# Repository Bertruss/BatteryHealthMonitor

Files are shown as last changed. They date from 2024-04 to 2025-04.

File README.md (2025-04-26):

## Battery Health Monitor

ATtiny45/85 based dedicated battery health monitor for embedded projects, with small status readout

# Setup Notes:
- lfuse set to 0xE2 to remove the DIV8 and set the clock to full 8mhz

*example: programming using the USBtinyISP via avrdude*
```
avrdude -c usbtiny -p t45 -U hfuse:w:0xE2:m
```
- The font data was intended to be written to eeprom on the chip to save flash, 
not knowing what the total compiled footprint of the code would be beforehand, I assumed I would need to be covetous of the limited 4k flash, and yet as development went on that seemed less and less necessary ¯\\_(ツ)_/¯. 

I used Microchip Studio for a lot of this development. If you want to not clear the eeprom every time you reflash the program storage, set the eeprom protect bit:

```
avrdude -c usbtiny -p t45 -U hfuse:w:0xD7:m
```

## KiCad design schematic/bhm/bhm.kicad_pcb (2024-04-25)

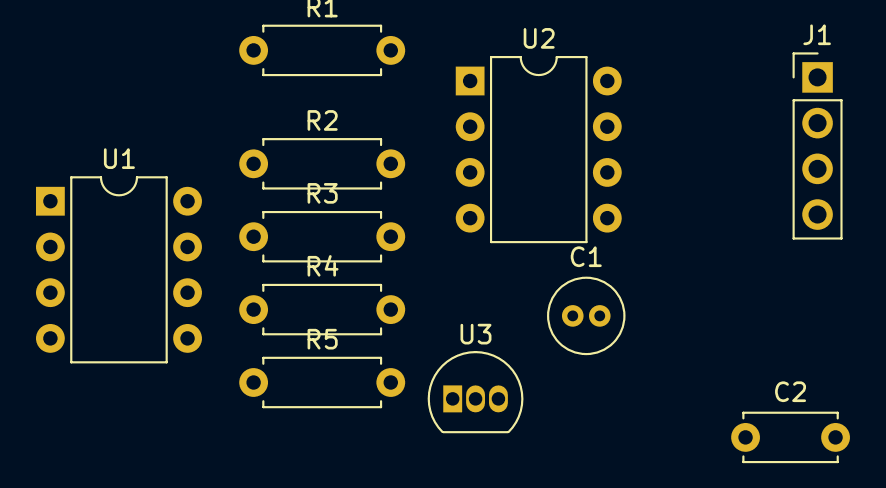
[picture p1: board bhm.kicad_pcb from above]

Board: 2 copper layers, 11 parts (0 on the bottom side), 9 nets, no tracks yet.

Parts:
C1: .33uf; C_Radial_D4.0mm_H7.0mm_P1.50mm
C2: .01uf; C_Disc_D5.0mm_W2.5mm_P5.00mm
J1: Conn_01x04; PinHeader_1x04_P2.54mm_Vertical
R1: 10k; R_Axial_DIN0207_L6.3mm_D2.5mm_P7.62mm_Horizontal
R2, R3, R4, R5: 300k; R_Axial_DIN0207_L6.3mm_D2.5mm_P7.62mm_Horizontal
U1: LM358; DIP-8_W7.62mm
U2: ATtiny45-20P; DIP-8_W7.62mm
U3: LM78L05_TO92; TO-92_Inline

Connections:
+8.4V: C1.1, R5.1, U1.8 (V+), U3.3 (VI)
GND: C1.2, C2.2, J1.4, R4.2, U1.4 (V-), U2.4 (GND), U3.2 (GND)
unnamed: J1.1, U2.5 (AREF/PB0)
unnamed: J1.2, U2.7 (PB2)
unnamed: C2.1, J1.3, R1.1, R3.1, U2.8 (VCC), U3.1 (VO)
unnamed: R4.1, R5.2, U1.3 (+)
unnamed: R2.2, R3.2, U1.2 (-)
unnamed: R2.1, U1.1, U2.2 (XTAL1/PB3)
unnamed: R1.2, U2.1 (~RESET/PB5)

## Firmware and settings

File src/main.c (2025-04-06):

#include "../include/fcpu.h"
#include "../include/TinyTWI.h"
#include "../include/TinyADC.h"
#include "../include/bhmDisplay.h"
#include "../include/bhmUtils.h"
#include "../include/SSD1306_driver.h"
#include <stdbool.h>
#include <avr/io.h>
#include <avr/sleep.h>
#include <util/delay.h>
#include "../include/bhmADC.h"

ISR(WDT_vect){ // toggle off the interrupt
	// watchdog timer interrupt disables automatically
    // sleep is disabled on wake via watchdog
}

int main(){
    cli(); // global interrupt disable
	//low_speed();
    twi_init(); // Initialize i2c
    adc_init(); // Configure ADC
	bhm_init(); // bhm specific configurations
    SSD1306_init(); // Setup the screen
	SSD1306_clear(); // Clear the screen mem
	configure_WDT_interrupt(); // configure timer based interrupt to wake sleep
	sei();
	bool test = 1;
	// Battery charge estimation 
	uint64_t total_charge_estimate = Ah; // assumption on bootup is that we start from full charge
	
	while(1){
		//test = !test; 
        uint32_t voltage = measure_battery_voltage();
        uint32_t current = measure_current_draw();
        uint8_t percent = basic_charge_estimate(voltage);
		//uint8_t percent = adv_charge_estimate(voltage, current, &total_charge_estimate);
		bool batt_warn = percent > 15 ? false : true; // below 15% trigger battery warning
		//calculate battery percentage estimate
        //calculate time-to-empty
        //update screen
		// ideas:
        // measure cell voltage O
        // transmit "bat low" if needed O
        // low power shut-off? X
        // low power beep? X
        // sleep for 500ms? update screen O
		update_display(percent, batt_warn, voltage, current);
		sleep_pause(); // 1s sleep pause
		_delay_ms(80);// acounting for other timing overhead, to reach 1.5s 
		
	}
}

void WDT_interrupt_enable(){
	 // enable the watchdog timer interrupt for sleep wake-up
	 WDTCR |= (1 << WDIE);
}				

void WDT_interrupt_disable(){
	WDTCR &= ~(1 << WDIE); // enable the watchdog timer interrupt for sleep wake-up
}

void configure_WDT_interrupt(){
	// TODO: consider configurable sleep cycle
    // TODO: PRR |= () //consider further power reduction
	// WDP3 WDP2 WDP1 WDP0
    WDTCR |= (1 << WDP2) | (1 << WDP1); //1 sec
}

void low_speed(){
	CLKPR = 0x80; // enable clk prescaler manipulation
	//(1 << CLKPCE) & !(1 << CLKPS3) & !(1 << CLKPS2) & !(1 << CLKPS1) & !(1 << CLKPS0);
	CLKPR |= (1 << CLKPS2); // | (1 << CLKPS0);
}

// triggers sleep mode with WDT triggered wake 
void sleep_pause(){
	cli();
	WDT_interrupt_enable();
	set_sleep_mode(SLEEP_MODE_IDLE);
	sei();
	sleep_enable();
	sleep_cpu(); //start slept conversion
	sleep_disable(); // wake
	WDT_interrupt_disable();
	cli();
}

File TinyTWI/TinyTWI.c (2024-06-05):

#include "TinyTWI.h"
#include "fcpu.h"
#include <stdint.h>
#include <stdbool.h>
#include <util/delay.h>

// fast mode, delays shortened because of other overhead 
#define __dwell_long() _delay_us(1.3) //low 1.3ns
#define __dwell_short() _delay_us(.8) //high .6ns

// refer to section 15 (pg.108) of the ATtiny25/45/85 Datasheet for more information

void twi_init(void){
    //initialize USI for I2C/TWI
	// Set the data register on the USI port
    USIDR = 0xFF;
    
    //initialize sda and scl to "high", default state
    PORT_TWI  |= (1 << SCL) | (1 << SDA);

	//intialize Data Direction on sda and scl as output val
	DDR_TWI |= (1 << SCL) | (1 << SDA);

    // Set the Control reg 
    USICR = (1 << USIWM1)| //Set the wire mode to TWI or I2C
            (1 << USICS1)| //set "external, pos-edge" clock source
            (1 << USICLK); //and set the 4-bit counter clk to software gen, via the (USITC) register
    // NOTE: for the sake of the 4-bit counter, this is an "external clock", 
    // so the counter is triggered on both edges. Hence a 4-bit (0-15 value) counter to count
    // shifting in and out an 8-bit value. The counter rolls over to 16 and triggers the overflow flag, 
    // which you can check to see if a full byte has been r/w

    // Set the status register
    /* TODO: experiment with pruning this.
    / USIPF and USIDC flags should never be set such that they need clearing in
    / this application. supposedly these are useful for multi-master arbitration but 
    / that won't appear in this programs intended use case.
    */
    USISR = (1 << USISIF) | //Clear the Start Condition Interrupt Flag
            (1 << USIOIF) | //Clear the Counter Overflow Interrupt Flag
            (1 << USIPF) | //Clear the Stop Condition Flag
            (1 << USIDC); //Clear Data Output Collision
}


void twi_disable(void){
	USICR &= !(1 << USIWM1); // disable TWI
}

void twi_enable(void){
	USICR |= (1 << USIWM1); // enable TWI
}

void twi_start(void){
    // outputs i2c start condition
    PORT_TWI &= ~(1 << SDA); // set SDA low
	__dwell_long();
    PORT_TWI &= ~(1 << SCL); // set clock low
	while ((PIN_TWI & (1 << SCL)) != 0); // wait for clock to pull low
	// other devices on the bus may hold clock high until they are ready, '
	// hence this wait.
	__dwell_long();
	//potentially, return status of start condition interrupt flag, start condition detection
}

void twi_stop(void){
    // outputs i2c stop condition
	USIDR = 0xff; //pulls SDA high?
	DDR_TWI |= (1 << SDA); //set SDA write
	PORT_TWI &= ~(1 << SDA); // set SDA low
	PORT_TWI |= (1 << SCL); // set SCL high
    while ((PIN_TWI & (1 << SCL)) == 0); //wait for SCL high
    __dwell_short();
    PORT_TWI |= (1 << SDA); // pull SDA high
    __dwell_long(); // just in case time-padding
}

uint8_t twi_byte_transfer(uint8_t buff, bool bit, enum xfer_type mode){
    //params:
    // buff - potential byte to write
    // bit - r/w single bit?
    // mode - transfer type is READ or WRITE
	USISR = (1 << USISIF) |
			(1 << USIOIF) |
			(1 << USIPF) |
			(1 << USIDC);
	USIDR = buff;
	
    if(mode == WRITE){
        DDR_TWI |= (1 << SDA); // data direction : write
		USIDR = buff; // move the data to the USI data register
    }
	else{ // READ
        DDR_TWI &= ~(1 << SDA); // data direction : read
    }

    if(bit){ //only read or write single bit
        USISR |= (0xE << USICNT0); //overflow with 1 bit
    }   
	
    // following loop will shift the data register onto the sda line (or vice versa depending on ddr setting) by toggling the clock
	PORT_TWI |= (1 << SDA); // "Release" sda
    do {
		__dwell_short();
		USICR = (1 << USIWM1) | (1 << USICS1) | (1 << USICLK) | (1 << USITC); // toggle the clock
		while ((PIN_TWI & (1 << SCL)) == 0); //wait for the clock to pull high
        __dwell_long();
        USICR = (1 << USIWM1) | (1 << USICS1) | (1 << USICLK) | (1 << USITC); // toggle the clock /* USICR = (1 << USIWM1) | (1 << USICS1) | (1 << USICLK) | (1 << USITC); */	
	}
    while((USISR & (1 << USIOIF)) == 0); // Check for counter overflow
	
    //__dwell_long();
    uint8_t data = USIDR;
    return data;
}

bool twi_transmission (uint8_t addr, uint8_t* buff, uint16_t length, enum xfer_type mode){
    twi_start();
    // Transmission Setup
    // Concatenate the address and transmit mode
    uint8_t ack;
	addr = (addr << 1) | mode;
    twi_byte_transfer(addr, false, WRITE);
	if(twi_byte_transfer(0x00, true, READ) != 0x00){ // check ack
		twi_stop();
		return false; // ACK failed
    }
	
    // Read or Write loop
    do{
        // read/write next byte
        *buff = twi_byte_transfer(*buff, false, mode);
		ack = twi_byte_transfer(0x00, true, 0x01^mode); // read/write ack bit
        buff++; // shift buffer pointer/index forward
		length--;
    }while(length && (ack == 0x00));
	
    //if read mode, end with NACK
    if(mode == READ){
        twi_byte_transfer(0x01, true, WRITE);
    }
	
    twi_stop();
	return (ack == 0x00);
}

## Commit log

2024-03-05 implementing small USI I2C
2024-03-06 WIP i2c implementation. considering not implementing read, out of laziness
2024-03-09 initializing display driver code. should be pretty minimal
2024-03-10 unless I'm mistaken, transfer code complete
    [TinyTWI.c]
2024-03-10 i2c code is probably done
2024-03-11 fixing multiple errors, missing semicolons, etc
    [TinyTWI.c]
2024-03-11 fixing some last inconsistencies
    [TinyTWI.c]
2024-03-16 initiliazing ADC code. I'll admit, I haven't even looked at the documentation yet so maybe this is unnecessary
2024-03-16 fixing twi bug that sent ack instead of nack to terminate a read mode.
    [TinyTWI.c]
2024-03-20 added various battery health display specific functions
2024-03-25 outlining ADC usage
2024-03-25 debugging, fixed compile time issues
    [TinyTWI.c]
2024-03-26 merging main into adc
2024-03-27 initial commit of circuit design. using KiCAD.
    [bhm.kicad_pcb, bhm.kicad_sch]
2024-03-28 adding KiCad schematic
    [bhm.kicad_sch]
2024-04-04 reworked to use differential opamp
    [bhm.kicad_sch]
2024-04-04 reworking main function to be closer to planned solution
    [batteryHealthMonitor.c]
2024-04-04 consolidating bhm specific sources to more generic lib folder. creating specific Utils files. copying over ADCscale files which are really specific to this use case.
2024-04-05 updating schematic with footprints also fixing terrible layout
    [bhm.kicad_sch]
2024-04-05 implemented functions to measure battery voltage with vcc compensation
2024-04-11 there's no power operator in c -_-
2024-04-11 Fixing adc conversion, adding back reference voltage which is accurate to the function of the bhm circuitry
    [bhmUtils.c]
2024-04-11 switching off reference voltage after measurement
2024-04-11 slight rework, update_display for voltage from 16 to 32 bit
    [batteryHealthMonitor.c]
2024-04-11 voltage from 16 to 32 bits
2024-04-11 bug-fixing, updating data-types and removing unused variables
    [TinyADC.c, batteryHealthMonitor.c]
2024-04-25 adding adc sleep-read
2024-04-25 making the adc read use the sleep/low-noise functionality
    [bhmUtils.c]
2024-04-25 testing gain settings with expected current sensing configuration
2024-04-25 testing out generating some preliminary pcb layouts
    [bhm.kicad_pcb]
2024-05-07 Adding flexibility to adc input selection
2024-05-07 assuming all lipos work this way... added cell number configuration parameter
2024-05-08 flashing out ADC changes to utilization stages
2024-05-08 adjustments to schematic
    [bhm.kicad_sch]
2024-05-08 interrupt test
2024-05-08 added blurb to screen driver code
2024-05-08 fixing numerous syntax errors
    [TinyADC.c]
2024-05-25 multiple changes to reduce size. tracking down bug with ADC.
    [TinyADC.c, batteryHealthMonitor.c, bhmUtils.c]
2024-06-05 removing explicit function for disabling the digital input buffer. seems that any analog read pin would only need to do this once, so it should be configured in a setup function.
2024-06-05 adding some test functions for reading the output of the ADC.
2024-06-05 using averaging to stabilize ADC jitter
    [bhmUtils.c]
2024-06-24 Added power throughhole solder points. reorg'd schematic for low side current measurement
    [bhm.kicad_sch]
2025-01-26 adding example fuse flash to README just so I don't forget how next time
2025-01-26 renaming ADCscale to reflect the fact the values therein are specific to the BHM use case. this is preemptive to expanding the constants declared here.
2025-03-07 added several useful defines. 1e8 fixed point. look up table to map voltages to charge estimate.
2025-03-07 genericized 3 digit num display. added current readout
2025-03-07 added current draw measurement, added multi-modal charge estimation
2025-03-12 adding constant describing the number of amps corresponding to volts sensed at the ADC pin
2025-03-12 Due to the fact current measurements will need to be much higher in range than voltage measurements, added optional extra digit
2025-03-12 potentially fixing math for calculating measured current. might still be wrong, idk
    [bhmUtils.c]
2025-03-16 refactoring adc usage for size, changing fixed point to be a binary rather than decimal value.
    [bhmUtils.c, main.c]
2025-04-06 WIP adding math utils to approximate nonlinear charge/voltage relationship instead of using lookuptable, though the current lut was used to derive the function. function will be included in future co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
2025-04-06 small sim for prototyping circuit
2025-04-06 updating schematic values
2025-04-06 logic testing for charge estimation.
2025-04-26 added ms time tracker using timer/counter1
